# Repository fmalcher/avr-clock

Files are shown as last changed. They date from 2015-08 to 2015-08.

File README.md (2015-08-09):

# Alarm clock with binary output, LCD and DCF77

This project features a working alarm clock with HD44780 compatible display, binary output and DCF77 sync.
It is built using an ATmega16.

Feel free to fork, contribute or ask questions.

## Demonstration

Bau einer Binäruhr (https://www.youtube.com/watch?v=sluBzaCNyI8)

## Issues
* Debouncing does not work correctly
* DCF77 implementation could be much more efficient

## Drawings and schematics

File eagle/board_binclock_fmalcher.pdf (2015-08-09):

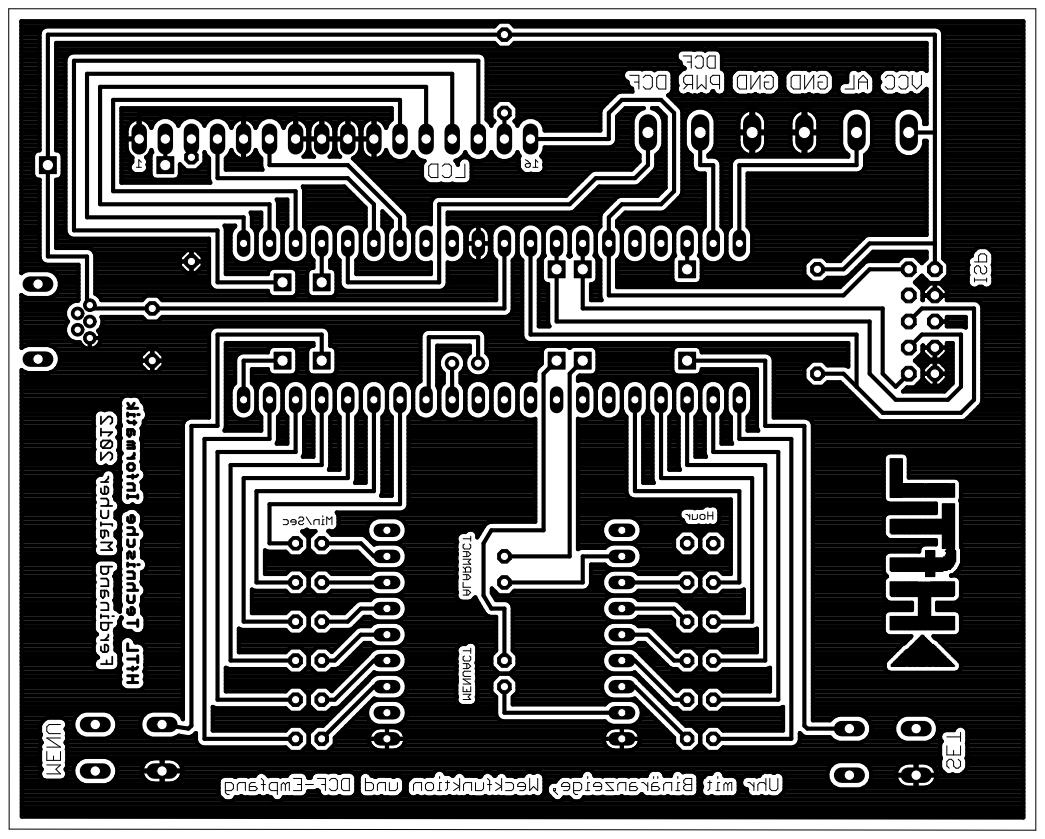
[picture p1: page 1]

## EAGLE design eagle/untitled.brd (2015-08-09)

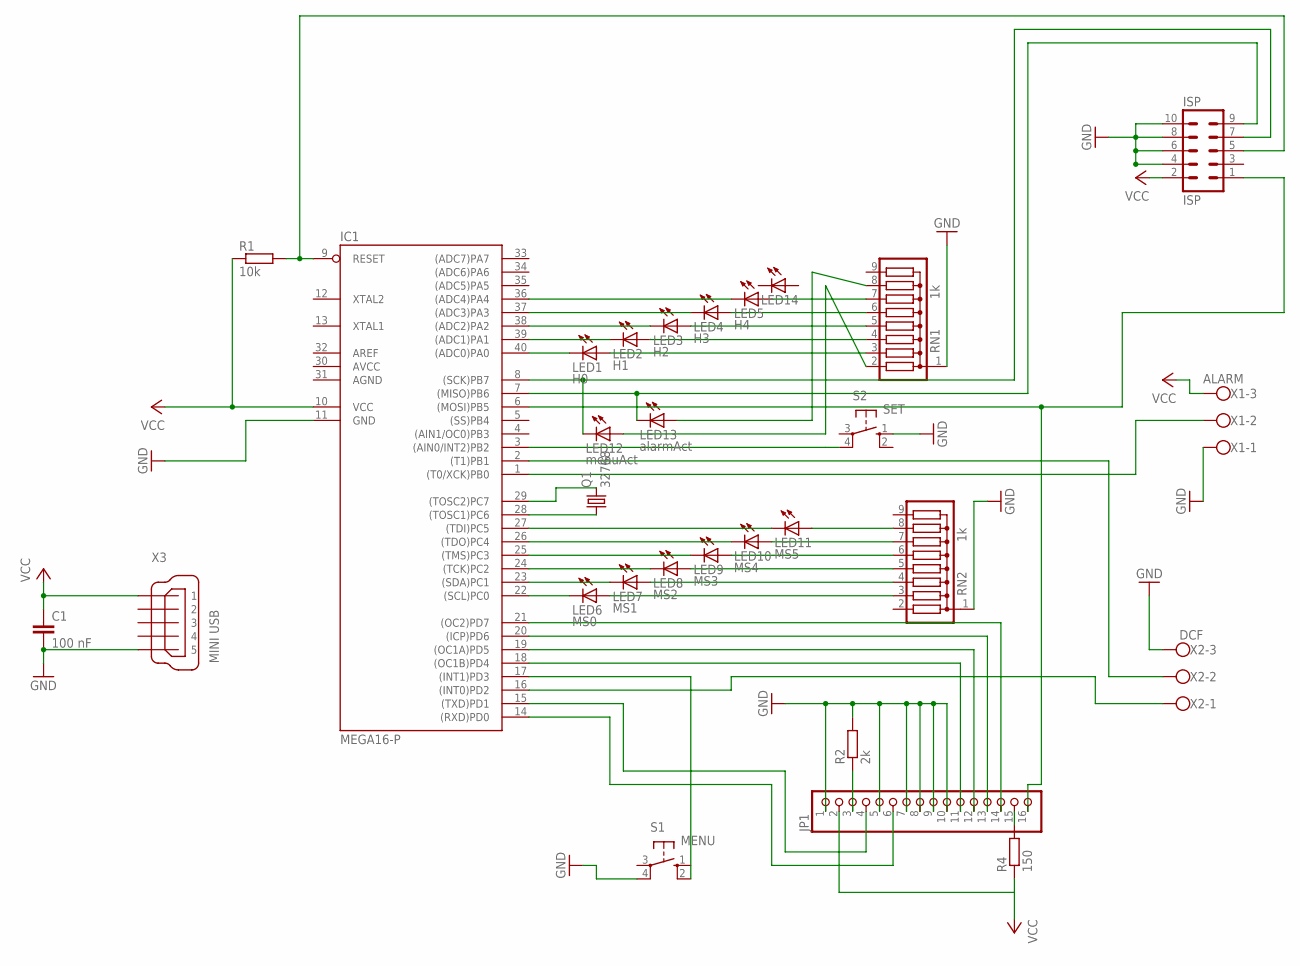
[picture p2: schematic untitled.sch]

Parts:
C1: 100 nF; C050-025X075
IC1: MEGA16-P; DIL40
ISP: ISP; ML10
JP1: PINHD-1X16; 1X16
LED1: H0; LED3MM
LED2: H1; LED3MM
LED3: H2; LED3MM
LED4: H3; LED3MM
LED5: H4; LED3MM
LED6: MS0; LED3MM
LED7: MS1; LED3MM
LED8: MS2; LED3MM
LED9: MS3; LED3MM
LED10: MS4; LED3MM
LED11: MS5; LED3MM
LED12: menuAct; LED3MM
LED13: alarmAct; LED3MM
LED14: LED3MM
Q1: 32768; TC26V
R1: 10k; 0207/10
R2: 2k; 0207/10
R4: 150; 0204/7
RN1, RN2: 1k; SIL9
S1: MENU; B3F-10XX
S2: SET; B3F-10XX
X1: ALARM; W237-133
X2: DCF; W237-133
X3: MINI USB; 32005-601

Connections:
AGND: IC1.31 (AGND)
AVCC: IC1.30 (AVCC)
GND: C1.2, IC1.11 (GND), ISP.4, ISP.6, ISP.8, ISP.10, JP1.1, JP1.5, JP1.7, JP1.8, JP1.9, JP1.10, R2.2, RN1.1, RN2.1, S1.4 (P1), S2.1 (S), X1.1, X2.3, X3.5
unnamed: IC1.40 ((ADC0)PA0), LED1.K (C)
unnamed: IC1.39 ((ADC1)PA1), LED2.K (C)
unnamed: IC1.38 ((ADC2)PA2), LED3.K (C)
unnamed: IC1.37 ((ADC3)PA3), LED4.K (C)
unnamed: IC1.36 ((ADC4)PA4), LED5.K (C)
unnamed: IC1.22 ((SCL)PC0), LED6.K (C)
unnamed: IC1.23 ((SDA)PC1), LED7.K (C)
unnamed: IC1.24 ((TCK)PC2), LED8.K (C)
unnamed: IC1.25 ((TMS)PC3), LED9.K (C)
unnamed: IC1.26 ((TDO)PC4), LED10.K (C)
unnamed: IC1.27 ((TDI)PC5), LED11.K (C)
unnamed: IC1.21 ((OC2)PD7), JP1.14
unnamed: LED11.A, RN2.8
unnamed: LED10.A, RN2.7
unnamed: LED9.A, RN2.6
unnamed: LED8.A, RN2.5
unnamed: LED7.A, RN2.4
unnamed: IC1.29 ((TOSC2)PC7), Q1.2
unnamed: IC1.28 ((TOSC1)PC6), Q1.1
unnamed: LED1.A, RN1.3
unnamed: LED2.A, RN1.4
unnamed: LED3.A, RN1.5
unnamed: LED4.A, RN1.6
unnamed: LED5.A, RN1.7
unnamed: IC1.9 (RESET), ISP.5, R1.2
unnamed: IC1.1 ((T0/XCK)PB0), X1.2
unnamed: IC1.6 ((MOSI)PB5), ISP.1, JP1.16
unnamed: IC1.8 ((SCK)PB7), ISP.7, LED12.K (C)
unnamed: LED6.A, RN2.3
unnamed: IC1.20 ((ICP)PD6), JP1.13
unnamed: IC1.19 ((OC1A)PD5), JP1.12
unnamed: IC1.18 ((OC1B)PD4), JP1.11
unnamed: JP1.3, R2.1
unnamed: IC1.15 ((TXD)PD1), JP1.4
unnamed: IC1.17 ((INT1)PD3), S1.2 (S1)
unnamed: IC1.14 ((RXD)PD0), JP1.6
unnamed: IC1.7 ((MISO)PB6), ISP.9, LED13.K (C)
unnamed: IC1.16 ((INT0)PD2), X2.1
unnamed: IC1.2 ((T1)PB1), X2.2
unnamed: LED12.A, RN1.2
unnamed: LED13.A, RN1.8
unnamed: IC1.3 ((AIN0/INT2)PB2), S2.4 (P1)
unnamed: JP1.15, R4.2
VCC: C1.1, IC1.10 (VCC), ISP.2, JP1.2, R1.1, R4.1, X1.3, X3.1

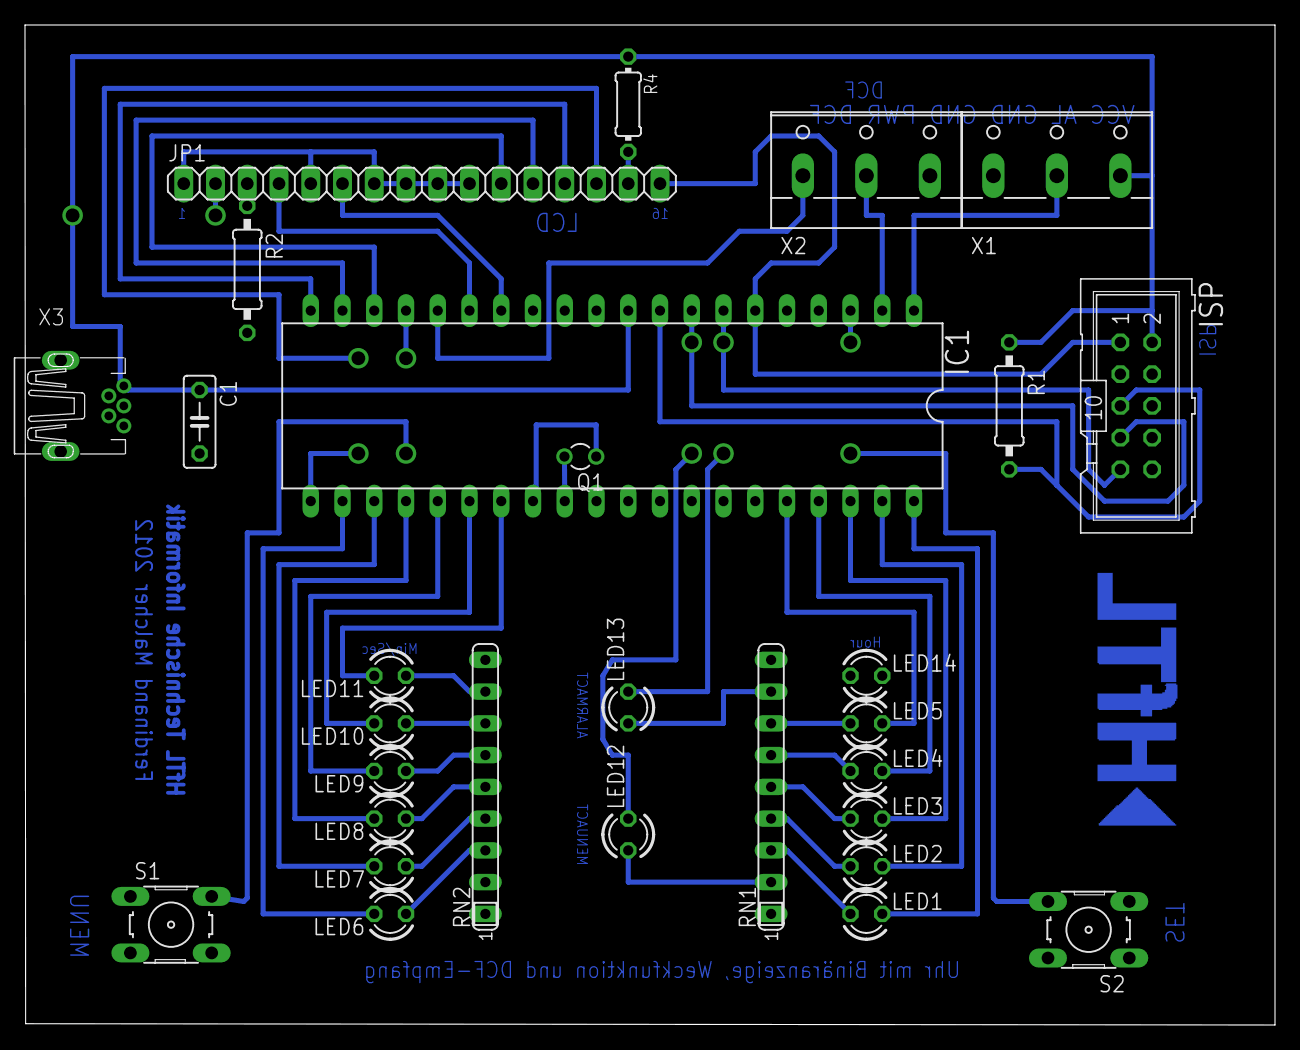
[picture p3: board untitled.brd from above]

Board: 2 copper layers, 100.0 x 80.0 mm, 29 parts (0 on the bottom side), 45 nets.

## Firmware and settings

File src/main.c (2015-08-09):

/* Author: Ferdinand Malcher
 * Project: Clock project, HfTL Computer Engineering 2012
 */

#include <avr/io.h>
#include <stdio.h>
#include <stdlib.h>
#include <string.h>
#include <stdint.h>
#include <avr/eeprom.h>
#include <avr/interrupt.h>
#include <util/delay.h>
#include <avr/sleep.h>

#include "main.h"
#include "lcd.h"

#include "functions.c"


#include "isrint0.c"
#include "isrint1.c"
#include "isrint2.c"
#include "isrtimer0.c"
#include "isrtimer1.c"
#include "isrtimer2.c"





int main(void){
	//disable JTAG (must be done twice)
	MCUCSR |= (1 << JTD);
	MCUCSR |= (1 << JTD);

	//Pin and port setting
	DDRH  = 0b11111111;
	PORTH = 0b00000000;
	
	DDRMS  = 0b11111111;
	PORTMS = 0b00000000;

	DDRB = 0b11111011;
	PORTB = 0b00111100;
	
	DDRD = 0b11110011;
	PORTD |= 0b00001100;
	
	lcd_init();
	lcd_clear();
	
	readfromeeprom();
	
	//INT0 (DCF) (is being enabled in while1-loop)
	MCUCR |= (1 << ISC00);
	MCUCR &= ~(1 << ISC01);
	
	
	//INT1 (Menu button)
	MCUCR |= (1 << ISC11);
	MCUCR &= ~(1 << ISC10);
	GICR |= (1 << INT1);
	
	//INT2 (Set button)
	MCUCR &= ~(1 << ISC2);
	GICR |= (1 << INT2);
	
	//Timer0
	TCCR0 |= (1 << CS01) | (1 << CS00);
	TCCR0 &= ~(1 << CS02);
	
	//Timer 1 (buzzer)
	TCCR1B &= ~(1 << WGM13); //WGM13 = 0
	TCCR1B |= (1 << WGM12);  //WGM12 = 1
	TCCR1A &= ~(1 << WGM11) & ~(1 << WGM10); // WGM11 = 0; WGM10 = 0
    
	TCCR1B |= (1 << CS10); //prescaler
    OCR1A = 600; //overflow compare
	
	
	
	
	//Timer2 (1 sec)
	TIMSK |= (1 << TOIE2);
	ASSR |= (1 << AS2);
	TCCR2 |= (1 << CS22) | (1 << CS20);
	
	
	
	
	
	sei();
	
	set_sleep_mode(SLEEP_MODE_IDLE);
	sleep_enable();
	
	
	//show time (time is shown when returning from menu)
	returnFromMenu = 1;

	while(1){
	
		//debounce
		_delay_ms(20);
    	if(p1){
        	p1--;
   		}
    	if(p2){
        	p2--;
    	}
		
	
		//enable DCF interrupts if there is no more waiting time
		if(dcfWait == 0 && dcfAct == 1){
			PORTB |= (1 << PB1); //DCF power enable
			GICR |= (1 << INT0);
		}
		
		/* switch on alarm when:
		 * alarm is enabled AND not already running AND
		 * - alarm time is reached AND no snooze counter running OR
		 * - snooze counter is finished
		 */
		if(alarmAct == 1 && alarmStatus() == 0 && (((hAlarm == h && mAlarm == m) && snoozeCnt == 0) || (snoozeCnt == 1))){
			setAlarm(1);
		}
		//switch off alarm if disabled but still running
		if(alarmStatus() == 1 && alarmAct == 0){
			setAlarm(0);
		}


		//write stuff to LCD		
		if(setlcd == 1){
			if(menuAct == 1){ //show menu
				lcd_clear();
				lcd_string(menuTxt[menuPos]);
				
				if(menuPos == 1 || menuPos == 2 || menuPos == 4 || menuPos == 5 || menuPos == 6){
					lcd_setcursor(0,1);
					lcd_string("> ");
				}
				
				
				//DISPLAY LIGHT
				if(menuPos == 0){
					if(lightStatus() == 1){
						writeOn();
					}else{
						writeOff();
					}
				
				//HOUR
				}else if(menuPos == 1){
					itoa(h, buf, 10);
					if(h < 10) lcd_string("0");
					lcd_string(buf);

				//MIN
				}else if(menuPos == 2){
					itoa(m, buf, 10);
					if(m < 10) lcd_string("0");
					lcd_string(buf);
					
				//ENABLE ALARM
				}else if(menuPos == 3){
					if(alarmAct == 1){
						writeOn();
					}else{
						writeOff();
					}					
				
				//ALARM HOUR
				}else if(menuPos == 4){
					itoa(hAlarm, buf, 10);
					if(hAlarm < 10) lcd_string("0");
					lcd_string(buf);

				//ALARM MIN
				}else if(menuPos == 5){
					itoa(mAlarm, buf, 10);
					if(mAlarm < 10) lcd_string("0");
					lcd_string(buf);
				
				//SNOOZE TIME
				}else if(menuPos == 6){
					itoa(snoozeMin, buf, 10);
					lcd_string(buf);
					if(snoozeMin < 10) lcd_string(" ");
				
				//DCF SYNC
				}else if(menuPos == 7){
					if(dcfAct == 1){
						writeOn();
					}else{
						writeOff();
					}
					
				//BINARY DISPLAY
				}else if(menuPos == 8){
					if(binDspl == 1){
						writeOn();
					}else{
						writeOff();
					}
					
				//BINARY MIN/SEC
				}else if(menuPos == 9){
					lcd_setcursor(0,1);
					if(binSec == 1){
						lcd_string("> Sec");
					}else{
						lcd_string("> Min");
					}
					
				}
				
			}else{ //show normal time
				if(returnFromMenu == 1){
					returnFromMenu = 0;
					
					savetoeeprom();					
					
					lcd_clear();
					lcd_setcursor(6,0);
					lcd_string("TIME");
				}
				
				
				//write time to display
				lcd_setcursor(4,1);
				
				if(h < 10) lcd_string("0");
				itoa(h, buf, 10);
				lcd_string(buf);
			
				lcd_string(":");
	
				if(m < 10) lcd_string("0");
        		itoa(m, buf, 10);
	        	lcd_string(buf);			
	
				lcd_string(":");

				if(s < 10) lcd_string("0");
	        	itoa(s, buf, 10);
    	    	lcd_string(buf);
    	    }
    	    
    	    setlcd = 0;
    	}
	sleep_mode();
	}

	return 0;
}

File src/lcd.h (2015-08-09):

// Ansteuerung eines HD44780 kompatiblen LCD im 4-Bit-Interfacemodus
// http://www.mikrocontroller.net/articles/AVR-GCC-Tutorial/LCD-Ansteuerung
//
 
#ifndef LCD_ROUTINES_H
#define LCD_ROUTINES_H

#include <avr/pgmspace.h>
////////////////////////////////////////////////////////////////////////////////
// Pinbelegung für das LCD, an verwendete Pins anpassen
// alle Pins müssen in einem Port liegen
// die 4 Bit für die Daten müssen zusammenliegen, können aber an einer
// beliebigen Postion anfangen  
 
//  LCD DB4-DB7 <-->  PORTD Bit PD4-PD7
#define LCD_PORT      PORTD
#define LCD_DDR       DDRD

// LCD Datenbus, Bitnummer des untersten Bits D4, kann auf den
// Portbits 0..4 liegen

#define LCD_DB        PD4
 
//  LCD RS      <-->  PORTD Bit PD2     (RS: 0=Data, 1=Command)
#define LCD_RS        PD1
 
//  LCD EN      <-->  PORTD Bit PD3     (EN: 1-Impuls für Daten)
#define LCD_EN        PD0
 
////////////////////////////////////////////////////////////////////////////////
// LCD Ausführungszeiten (MS=Millisekunden, US=Mikrosekunden)
 
#define LCD_BOOTUP_MS           15
#define LCD_ENABLE_US           1
#define LCD_WRITEDATA_US        46
#define LCD_COMMAND_US          42
 
#define LCD_SOFT_RESET_MS1      5
#define LCD_SOFT_RESET_MS2      1
#define LCD_SOFT_RESET_MS3      1
#define LCD_SET_4BITMODE_MS     5
 
#define LCD_CLEAR_DISPLAY_MS    2
#define LCD_CURSOR_HOME_MS      2
 
////////////////////////////////////////////////////////////////////////////////
// Zeilendefinitionen des verwendeten LCD
// Die Einträge hier sollten für ein LCD mit einer Zeilenlänge von 16 Zeichen passen
// Bei anderen Zeilenlängen müssen diese Einträge angepasst werden
 
#define LCD_DDADR_LINE1         0x00
#define LCD_DDADR_LINE2         0x40
#define LCD_DDADR_LINE3         0x10
#define LCD_DDADR_LINE4         0x50
 
////////////////////////////////////////////////////////////////////////////////
// Initialisierung: muss ganz am Anfang des Programms aufgerufen werden.
void lcd_init( void );
 
////////////////////////////////////////////////////////////////////////////////
// LCD löschen
void lcd_clear( void );
 
////////////////////////////////////////////////////////////////////////////////
// Cursor in die 1. Zeile, 0-te Spalte
void lcd_home( void );
 
////////////////////////////////////////////////////////////////////////////////
// Cursor an eine beliebige Position 
void lcd_setcursor( uint8_t spalte, uint8_t zeile );
 
////////////////////////////////////////////////////////////////////////////////
// Ausgabe eines einzelnen Zeichens an der aktuellen Cursorposition 
void lcd_data( uint8_t data );
 
////////////////////////////////////////////////////////////////////////////////
// Ausgabe eines Strings an der aktuellen Cursorposition 
// String liegt im RAM
void lcd_string( const char *data );

////////////////////////////////////////////////////////////////////////////////
// Ausgabe eines Strings an der aktuellen Cursorposition
// String liegt im Flash 
void lcd_string_P( PGM_P data );
 
////////////////////////////////////////////////////////////////////////////////
// Definition eines benutzerdefinierten Sonderzeichens.
// data muss auf ein Array[8] mit den Zeilencodes des zu definierenden Zeichens
// zeigen, Daten liegen im RAM
void lcd_generatechar( uint8_t code, const uint8_t *data );
 
////////////////////////////////////////////////////////////////////////////////
// Definition eines benutzerdefinierten Sonderzeichens.
// data muss auf ein Array[8] mit den Zeilencodes des zu definierenden Zeichens
// zeigen, Daten liegen im FLASH
void lcd_generatechar_P( uint8_t code, PGM_P data );
 
////////////////////////////////////////////////////////////////////////////////
// Ausgabe eines Kommandos an das LCD.
void lcd_command( uint8_t data );

////////////////////////////////////////////////////////////////////////////////
// LCD Befehle und Argumente.
// Zur Verwendung in lcd_command
 
// Clear Display -------------- 0b00000001
#define LCD_CLEAR_DISPLAY       0x01
 
// Cursor Home ---------------- 0b0000001x
#define LCD_CURSOR_HOME         0x02
 
// Set Entry Mode ------------- 0b000001xx
#define LCD_SET_ENTRY           0x04
 
#define LCD_ENTRY_DECREASE      0x00
#define LCD_ENTRY_INCREASE      0x02
#define LCD_ENTRY_NOSHIFT       0x00
#define LCD_ENTRY_SHIFT         0x01
 
// Set Display ---------------- 0b00001xxx
#define LCD_SET_DISPLAY         0x08
 
#define LCD_DISPLAY_OFF         0x00
#define LCD_DISPLAY_ON          0x04
#define LCD_CURSOR_OFF          0x00
#define LCD_CURSOR_ON           0x02
#define LCD_BLINKING_OFF        0x00
#define LCD_BLINKING_ON         0x01
 
// Set Shift ------------------ 0b0001xxxx
#define LCD_SET_SHIFT           0x10
 
#define LCD_CURSOR_MOVE         0x00
#define LCD_DISPLAY_SHIFT       0x08
#define LCD_SHIFT_LEFT          0x00
#define LCD_SHIFT_RIGHT         0x01
 
// Set Function --------------- 0b001xxxxx
#define LCD_SET_FUNCTION        0x20
 
#define LCD_FUNCTION_4BIT       0x00
#define LCD_FUNCTION_8BIT       0x10
#define LCD_FUNCTION_1LINE      0x00
#define LCD_FUNCTION_2LINE      0x08
#define LCD_FUNCTION_5X7        0x00
#define LCD_FUNCTION_5X10       0x04
 
#define LCD_SOFT_RESET          0x30
 
// Set CG RAM Address --------- 0b01xxxxxx  (Character Generator RAM)
#define LCD_SET_CGADR           0x40
 
#define LCD_GC_CHAR0            0
#define LCD_GC_CHAR1            1
#define LCD_GC_CHAR2            2
#define LCD_GC_CHAR3            3
#define LCD_GC_CHAR4            4
#define LCD_GC_CHAR5            5
#define LCD_GC_CHAR6            6
#define LCD_GC_CHAR7            7
 
// Set DD RAM Address --------- 0b1xxxxxxx  (Display Data RAM)
#define LCD_SET_DDADR           0x80
 
#endif 
